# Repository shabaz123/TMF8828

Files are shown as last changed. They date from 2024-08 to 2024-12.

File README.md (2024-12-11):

# TMF8828 Multi-Zone Time-of-Flight Sensor

# Introduction
This repository contains a project (hardware and software) related to the TMF8828 sensor. 

[Click here for information regarding the TMF8828](https://community.element14.com/products/manufacturers/ams_osram/b/blog/posts/engineer-to-engineer-understanding-time-of-flight-sensing).

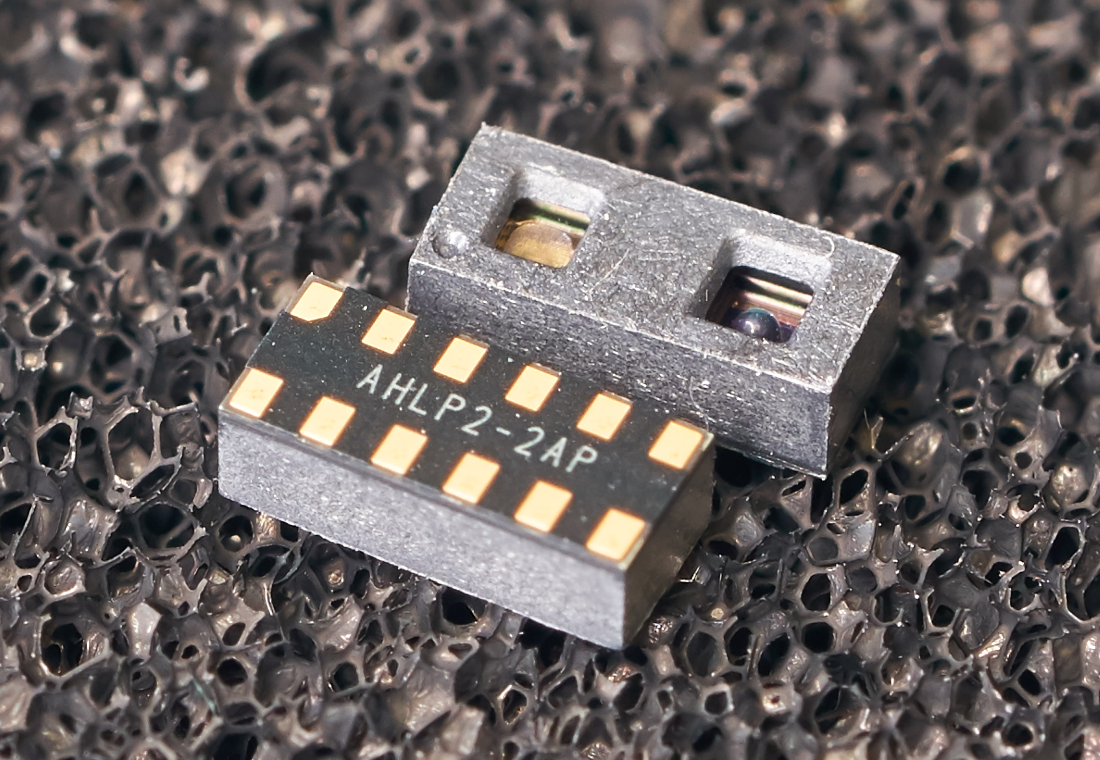
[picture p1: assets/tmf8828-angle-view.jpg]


**Caution**
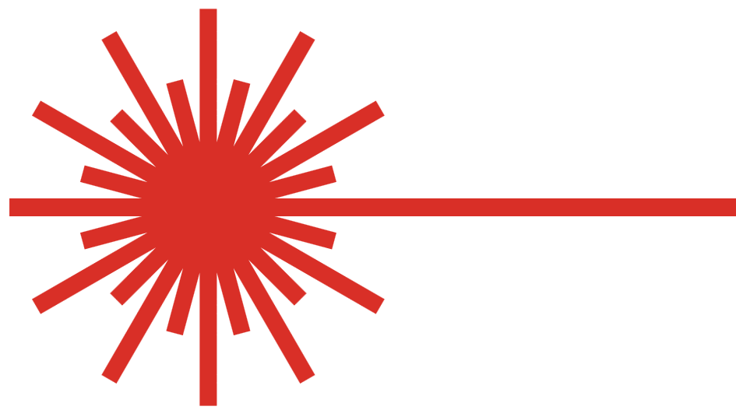
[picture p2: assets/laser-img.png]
 The device contains a laser. In the photo above, the aperture on the left (lighter color) contains the laser. The darker aperture on the right contains the sensor array.

# Circuit Diagram
The circuit shown below can be assembled onto a small board. It is designed to either interface with a Pi Pico board, or, alternatively, any other microcontroller with a 3.3V I2C interface. 

Some components are labeled DNF (Do Not Fit), depending on if you intend to use the board with a Pi Pico or with a different board.
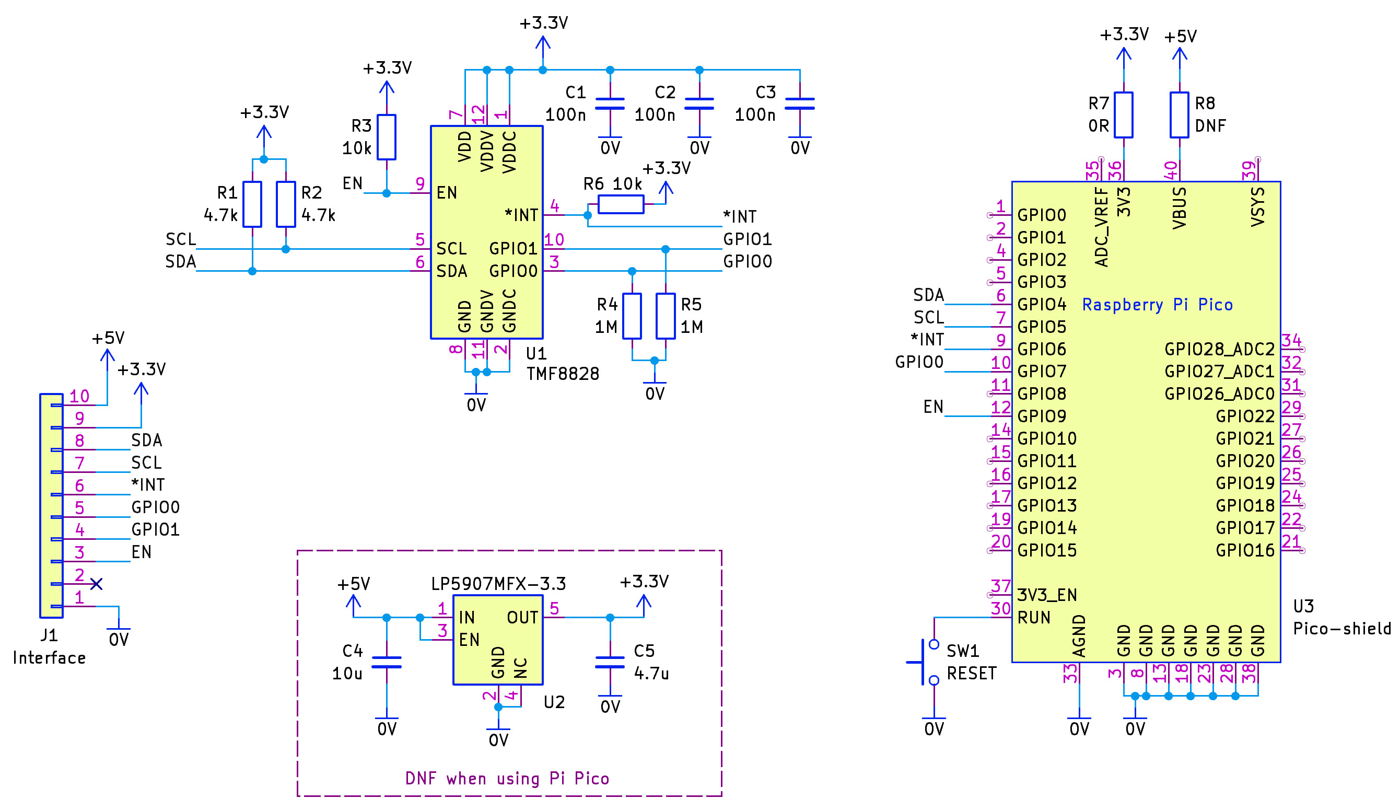
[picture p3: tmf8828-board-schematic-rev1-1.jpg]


Note: The diagram shown is for revision 1.1. The only difference between rev 1.0 and rev 1.1 is that the later revision connects the TMF8828 EN pin to GPIO9 on the Pi Pico. In rev 1.0, that connection was missing.

# PCB Layout
The KiCad files (requires KiCad V8.0 upward) are in the repo, as well as the generated Gerber files, ready for sending to a PCB factory. 

Currently, there are no known errors, but it has not undergone much testing beyond basic board bring-up, and running some code that appears to provide a response from the sensor.
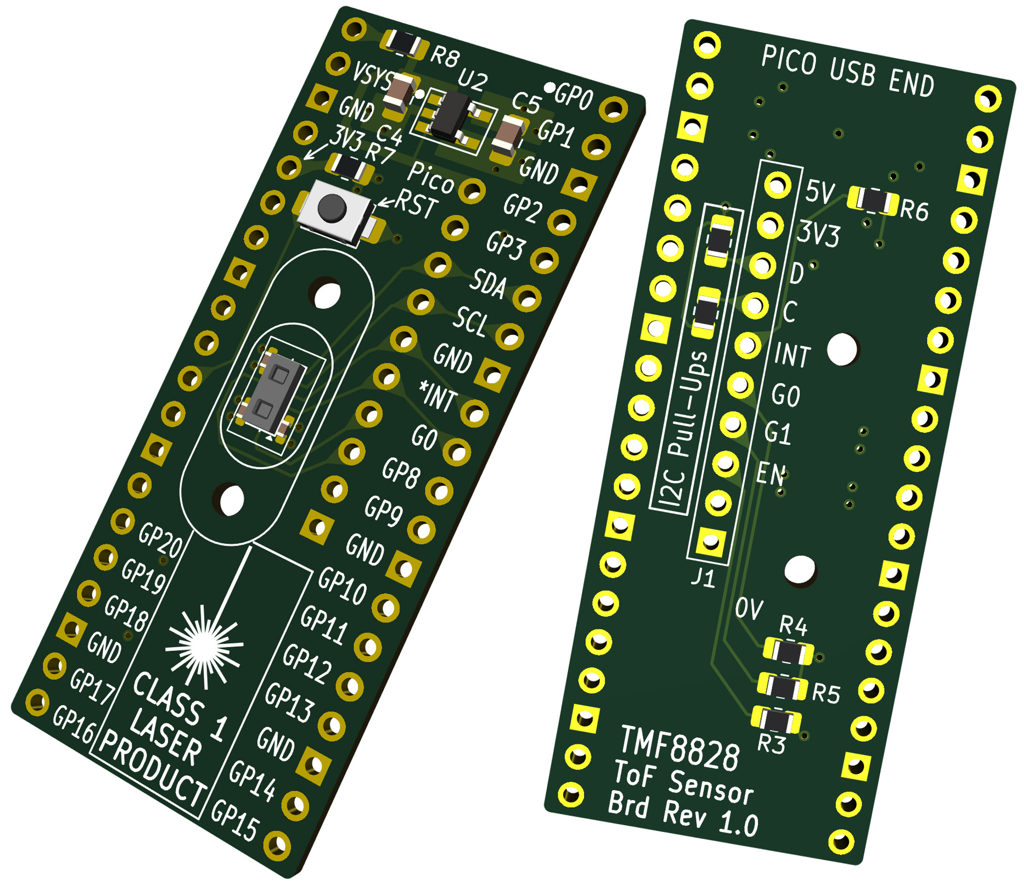
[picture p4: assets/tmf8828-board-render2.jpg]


# Source Code
The tmf8828_experiment_board folder contains a Pi Pico project (requires the [Pi Pico C/C++ SDK](https://www.raspberrypi.com/documentation/microcontrollers/c_sdk.html)). 

After building the code (follow the Pi Pico C/C++ SDK user instructions), hold down the BOOTSEL button on the Pi Pico, plug in the USB cable into the PC, release the BOOTSEL button, and then drag across the built .uf2 file onto the USB drive letter that appeared. The firmware will be uploaded into the Pi Pico, and it will automatically start running the code. 

The device will present a serial port, which can be opened using an serial console software, at 115200 baud, to see a stream of data in text form. 

The source code is based on the Unified Arduino driver for TMF8820/24/28 available under the **Software** section at the [AMS TMF8828 web page](https://ams-osram.com/products/sensors/direct-time-of-flight-sensors-dtof/ams-tmf8828-configurable-8x8-multi-zone-time-of-flight-sensor), and a modification of it from https://github.com/Zalmotek/renesas-ams-osram-pmod1/tree/main/firmware/C/TMF8828

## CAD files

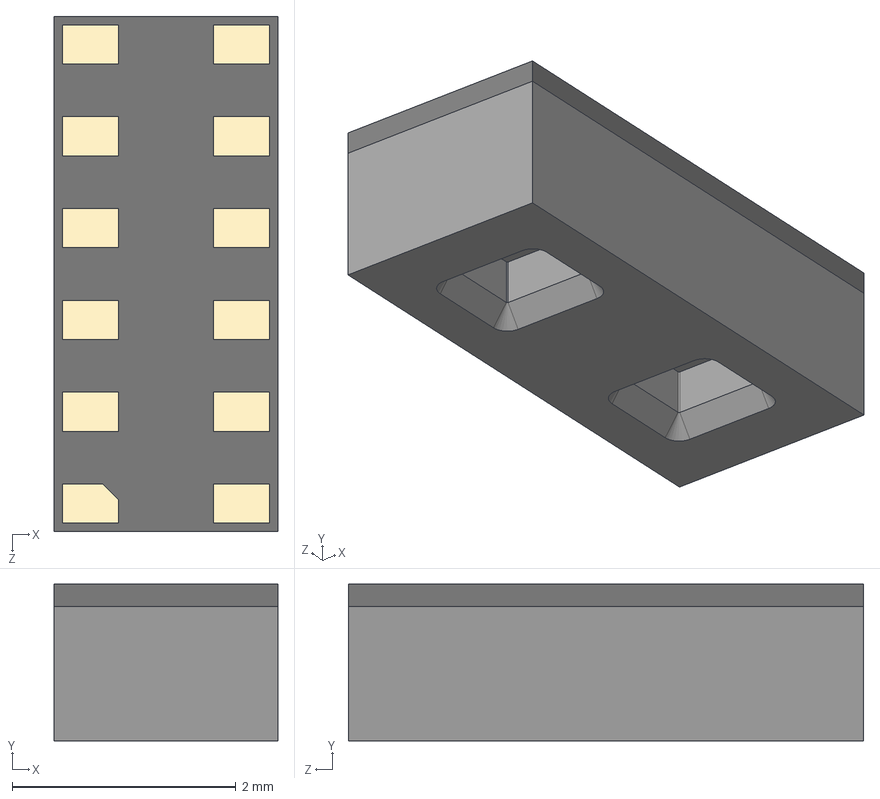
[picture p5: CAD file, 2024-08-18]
TMF8828-3D-Model.stp
2.00 x 1.40 x 4.60 mm

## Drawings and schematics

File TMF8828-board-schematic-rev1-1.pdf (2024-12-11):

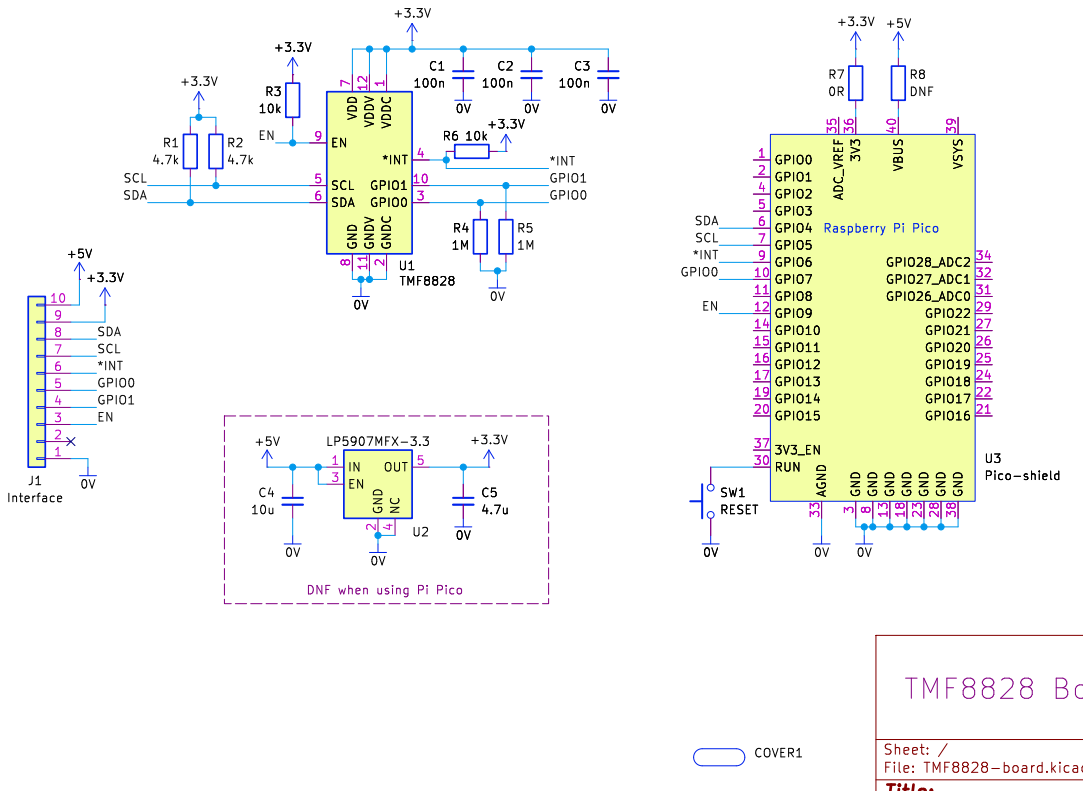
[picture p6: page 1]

Id: 1/1 Title: File: TMF8828-board.kicad_sch Sheet: /

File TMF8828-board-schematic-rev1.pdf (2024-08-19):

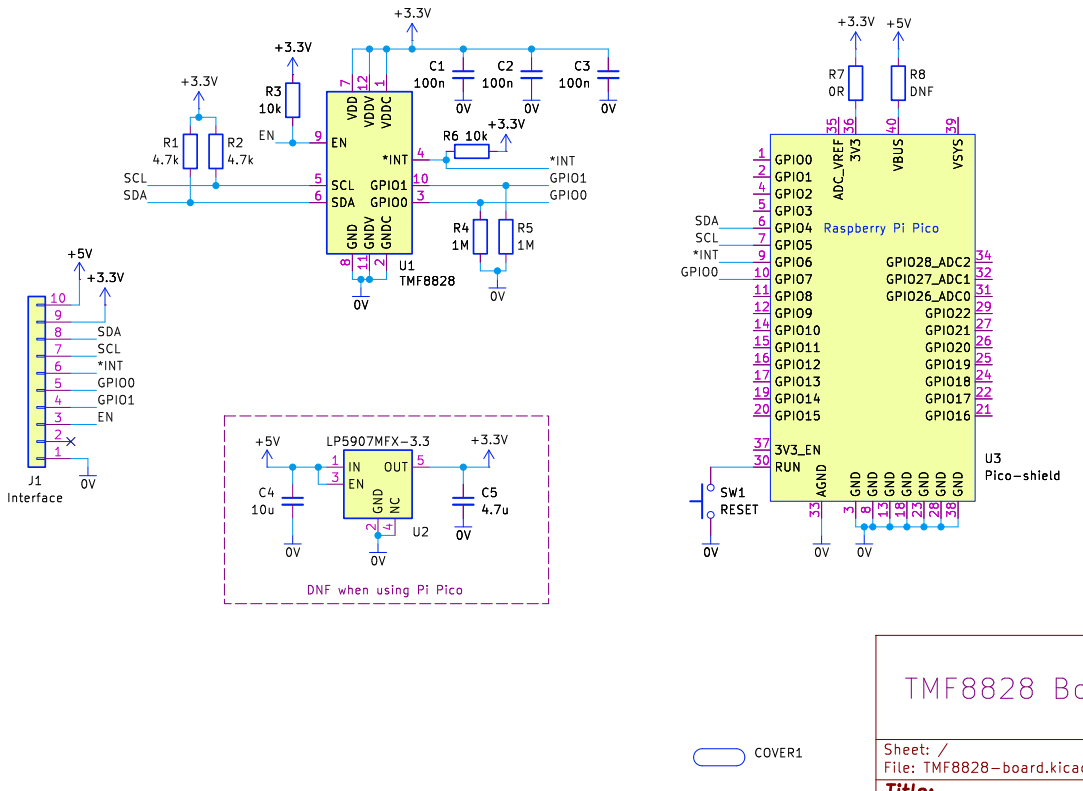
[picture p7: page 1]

Id: 1/1 Title: File: TMF8828-board.kicad_sch Sheet: /

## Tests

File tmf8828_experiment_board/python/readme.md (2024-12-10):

# These are python files for the talk to arduino via python

Python version 3.6 or higher is required.

## Virtual environment

Recommendation is to set-up a virtual environment. Open you favorite Windows PowerShell, VisualStudio Code or Spyder.
To install a virtual environement named env, and use it:
python -m venv env     
./env/Scripts/Activate.ps1    

## Requirements

pip install -r ./requirements.txt

## Scripts 

Please check on which COM port the Arduino is connected to your PC. Correct the com port in the python script to match
your PC.

To run a simple python script do this:

python talk_to_3_arduino_1MBaud.py

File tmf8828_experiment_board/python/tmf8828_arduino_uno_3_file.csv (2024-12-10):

Tmf8828 Arduino Uno + 2 tmf8828
#Vers | 3.224.52.27
#Vers | 3.224.52.27
#Conf | Period=132ms | KIter=250
#Obj | 67 | 0 | 21 | 16 | 239649 | 29 | 132 | 35 | 131 | 36 | 136 | 29 | 140 | 22 | 141 | 20 | 143 | 38 | 121 | 48 | 123 | 0 | 0 | 28 | 130 | 34 | 133 | 33 | 140 | 30 | 133 | 18 | 144 | 33 | 142 | 36 | 122 | 50 | 118 | 0 | 0 | 0 | 0 | 0 | 0 | 0 | 0 | 0 | 0 | 0 | 0 | 0 | 0 | 0 | 0 | 0 | 0 | 0 | 0
#Obj | 66 | 0 | 22 | 16 | 293593 | 33 | 129 | 46 | 130 | 43 | 136 | 31 | 141 | 30 | 143 | 26 | 145 | 45 | 113 | 47 | 111 | 0 | 0 | 32 | 131 | 46 | 130 | 41 | 141 | 32 | 132 | 22 | 144 | 40 | 140 | 44 | 113 | 48 | 110 | 0 | 0 | 0 | 0 | 0 | 0 | 0 | 0 | 0 | 0 | 0 | 0 | 0 | 0 | 0 | 0 | 0 | 0 | 0 | 0
#Obj | 65 | 0 | 22 | 0 | 344789 | 0 | 0 | 0 | 0 | 0 | 0 | 0 | 0 | 0 | 0 | 0 | 0 | 0 | 0 | 0 | 0 | 0 | 0 | 0 | 0 | 0 | 0 | 0 | 0 | 0 | 0 | 0 | 0 | 0 | 0 | 0 | 0 | 0 | 0 | 0 | 0 | 0 | 0 | 0 | 0 | 0 | 0 | 0 | 0 | 0 | 0 | 0 | 0 | 0 | 0 | 0 | 0 | 0 | 0
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

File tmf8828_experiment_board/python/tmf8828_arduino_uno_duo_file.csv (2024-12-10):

Tmf8828 Arduino Uno + 2 tmf8828
#Vers | 3.224.52.27
#Conf | Period=132ms | KIter=250
#Obj | 66 | 0 | 21 | 16 | 238425 | 28 | 255 | 40 | 255 | 37 | 255 | 31 | 255 | 25 | 255 | 20 | 255 | 40 | 255 | 40 | 255 | 0 | 0 | 29 | 255 | 39 | 255 | 38 | 255 | 33 | 255 | 18 | 255 | 32 | 255 | 42 | 255 | 42 | 255 | 0 | 0 | 0 | 0 | 0 | 0 | 0 | 0 | 0 | 0 | 0 | 0 | 0 | 0 | 0 | 0 | 0 | 0 | 0 | 0
#Obj | 65 | 0 | 20 | 13 | 292045 | 0 | 0 | 0 | 0 | 0 | 0 | 1819 | 28 | 1873 | 15 | 787 | 10 | 0 | 0 | 1840 | 23 | 0 | 0 | 0 | 0 | 0 | 0 | 1856 | 14 | 1831 | 17 | 820 | 10 | 1799 | 55 | 843 | 8 | 1852 | 15 | 0 | 0 | 0 | 0 | 0 | 0 | 0 | 0 | 0 | 0 | 0 | 0 | 1787 | 70 | 0 | 0 | 0 | 0 | 0 | 0
#Obj | 66 | 1 | 21 | 16 | 473017 | 29 | 255 | 39 | 255 | 37 | 255 | 32 | 255 | 13 | 255 | 42 | 255 | 39 | 255 | 42 | 255 | 0 | 0 | 27 | 255 | 38 | 255 | 35 | 255 | 32 | 255 | 13 | 255 | 41 | 255 | 37 | 255 | 42 | 255 | 0 | 0 | 0 | 0 | 0 | 0 | 0 | 0 | 0 | 0 | 0 | 0 | 0 | 0 | 0 | 0 | 0 | 0 | 0 | 0
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

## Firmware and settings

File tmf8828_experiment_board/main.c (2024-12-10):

/******************************
 * main.c
 * rev 1.0 Sep 2024 shabaz
 * ****************************/

#include <stdio.h>
#include <string.h>
#include "pico/stdlib.h"
#include "extrafunc.h"
#include "hardware/gpio.h"
#include "tmf8828.h"
#include "tmf8828_image.h"
#include "tmf8828_calib.h"
#include "tmf8828_shim.h"
#include "tmf8828_sensor.h"

// definitions
// set to 0 to run a simple app
// set to 1 to run the evaluation mode similar to the Arduino version from the manufacturer
#define EVAL_MODE 1

#define TOKEN_RESULT_ERROR 0
#define TOKEN_RESULT_OK 1
#define TOKEN_RESULT_LINE_COMPLETE 2
#define TOKEN_PROGRESS_NONE 0
#define TOKEN_PROGRESS_SEND 1
#define TOKEN_PROGRESS_RECV 2

// eval mode tmf states
#define TMF8828_STATE_DISABLED      0
#define TMF8828_STATE_STANDBY       1
#define TMF8828_STATE_STOPPED       2
#define TMF8828_STATE_MEASURE       3
#define TMF8828_STATE_ERROR         4


#define COL_RED printf("\033[31m")
#define COL_GREEN printf("\033[32m")
#define COL_YELLOW printf("\033[33m")
#define COL_BLUE printf("\033[34m")
#define COL_MAGENTA printf("\033[35m")
#define COL_CYAN printf("\033[36m")
#define COL_RESET printf("\033[0m")

// constants

// eval mode constants
extern const uint16_t configPeriod[3];
extern const uint16_t configKiloIter[3];
const uint8_t  configSpadId[3] = {15, 15, 15};
const uint16_t configLowThreshold = 100; // set the lower threshold to 10cm
const uint16_t configHighThreshold = 500; // set the upper threshold to 50cm
// select perstistence to be: 0==report every distance, even no distance; 1== report every distance that is a distance, 3== report distance only if 3x in range
const uint8_t configPersistance[3] = { 0, 1, 3 };
#define NR_LOG_LEVELS           7
// to increase/decrease logging
const uint8_t logLevels[ NR_LOG_LEVELS ] =
        { LOG_LEVEL_NONE,
          LOG_LEVEL_ERROR,
          LOG_LEVEL_CLK_CORRECTION,
          LOG_LEVEL_INFO,
          LOG_LEVEL_VERBOSE,
          LOG_LEVEL_I2C,
          LOG_LEVEL_DEBUG
        };

// global variables

uint8_t uart_buffer[305];
uint16_t uart_buffer_index = 0;
uint8_t do_echo = 1;
uint8_t token_progress = TOKEN_PROGRESS_NONE;
int expected_num = 0;
uint8_t byte_buffer[256];
uint8_t byte_buffer_index = 0;
uint16_t loop_tick = 0;

// eval mode global variables
//tmf8828Driver tmf8828[1];
extern tmf8828Driver tmf8828; // defined in tmf8828.c
extern int8_t stateTmf8828;              // current state of the device
extern int8_t configNr;                  // this sample application has only a few configurations it will loop through, the variable keeps track of that
int8_t persistenceNr;             // this is to keep track of the selected persistence setting (out of three for this sample application)
extern int8_t clkCorrectionOn;           // if non-zero clock correction is on
extern int8_t dumpHistogramOn;           // if non-zero, dump all histograms
uint8_t logLevelIdx;              // log level index into logLevels array
volatile uint8_t irqTriggered;    // interrupt is triggered or not
extern const unsigned long tmf8828_image_termination;
extern const unsigned long tmf8828_image_start;
extern const unsigned long tmf8828_image_finish;
extern const unsigned long tmf8828_image_length;
extern const unsigned char tmf8828_image[7128];
extern const uint8_t tmf8828_calib_0[192];
extern const uint8_t tmf8828_calib_1[192];
extern const uint8_t tmf8828_calib_2[192];
extern const uint8_t tmf8828_calib_3[192];



/************* prototypes ***************/
// eval mode prototypes
void eval_mode(void);
void print_eval_menu(void);

/************* functions ***************/

// print_buf_hex prints a buffer in hex format, up to 304 bytes
// 000: 00 01 02 03 04 05 06 07 08 09 0A 0B 0C 0D 0E 0F : 0123456789ABCDEF
void
print_buf_hex(uint8_t *buf, uint16_t len) {
    uint16_t i, j;
    uint8_t c;
    uint8_t index = 0;

    for (i = 0; i < len; i += 16) {
        COL_BLUE;
        printf("%03d: ", index);
        COL_CYAN;
        for (j = 0; j < 16; j++) {
            if (i + j < len) {
                printf("%02X ", buf[i + j]);
            } else {
                printf("   ");
            }
        }
        COL_BLUE;
        printf(": ");
        COL_GREEN;
        for (j = 0; j < 16; j++) {
            if (i + j < len) {
                c = buf[i + j];
                if ((c < 32) || (c > 126)) {
                    printf(".");
                } else {
                    printf("%c", c);
                }
            } else {
                printf(" ");
            }
        }
        printf("\n");
        index += 16;
    }
    COL_RESET;
}



// scan_uart_input fill the uart_buffer until a newline is received
// returns number of bytes if a newline is received, 0 otherwise
int
scan_uart_input(void) {
    int c;
    uint16_t num_bytes;
    c = getchar_timeout_us(1000);
    if (c == PICO_ERROR_TIMEOUT) {
        return 0;
    }

    if ((c == 8) || (c==127)) { // backspace pressed
        if (uart_buffer_index > 0) {
            uart_buffer_index--;
            if (do_echo) {
                putchar(8);
                putchar(' ');
                putchar(8);
            }
        }
        return 0;
    }
    if (c == 13) {
        // add a space to simplify token parsing
        uart_buffer[uart_buffer_index++] = ' ';
        uart_buffer[uart_buffer_index] = 0;
        num_bytes = uart_buffer_index;
        uart_buffer_index = 0;
        if (do_echo) {
            printf("\n");
        }
        return num_bytes;
    }
    uart_buffer[uart_buffer_index] = (uint8_t) c;
    if (do_echo) {
        putchar(c);
    }
    uart_buffer_index++;
    if (uart_buffer_index >= 300) {
        uart_buffer_index = 0;
    }
    return 0;
}

int decode_token(char *token) {
    unsigned int val;
    int retval = 0;
    if (strcmp(token, "device?") == 0) {
        printf("TMF8828 Experiment Board\n\r");
        // reset any state and variables
        token_progress = TOKEN_PROGRESS_NONE;
        expected_num = 0;
        byte_buffer_index = 0;
        return TOKEN_RESULT_LINE_COMPLETE;
    }
    if (strcmp(token, "recv") == 0) {
        if (expected_num == 0) {
            COL_RED;
            printf("No bytes expected\n");
            COL_RESET;
            return TOKEN_RESULT_LINE_COMPLETE;
        }
        byte_buffer_index = 0;
        retval = PICO_ERROR_GENERIC; // nothing to do for now
        if (retval == PICO_ERROR_GENERIC) {
            COL_RED;
            printf("No bytes read.\n");
            COL_RESET;
        } else {
            print_buf_hex(byte_buffer, expected_num);
        }
        return TOKEN_RESULT_LINE_COMPLETE;
    }
    if (strcmp(token, "end_tok") == 0) {
        return TOKEN_RESULT_LINE_COMPLETE;
    }
    // done
    COL_RED;
    printf("Unknown command: %s\n", token);
    COL_RESET;
    return TOKEN_RESULT_LINE_COMPLETE;
}

// Parse each space-separated token
int process_line(uint8_t *buf, uint16_t len) {
    int res;
    char token[20];
    uint16_t i = 0;
    uint16_t j = 0;
    if (len == 0) {
        return TOKEN_RESULT_ERROR;
    }
    while (i < len) {
        if (buf[i] == ' ') {
            token[j] = 0;
            //printf("token: %s\n", token);
            res = decode_token(token);
            if (res == TOKEN_RESULT_LINE_COMPLETE) {
                return TOKEN_RESULT_LINE_COMPLETE;
            }
            j = 0;
        } else {
            token[j] = buf[i];
            j++;
        }
        i++;
    }
    res = decode_token("end_tok");
}

int
main(void)
{
    int numbytes;

    stdio_init_all();
    sleep_ms(3000);
    led_setup();
    printf("TMF8828 Experiment Board\n");
    configurePins();
    if (EVAL_MODE) {
        eval_mode(); // this does not return
    }
    // the rest of the code here is a simple app example
    TMF8828_constructor();
    TMF8828_factoryCalibration(0, false); //must precede the startMeasuring function
    TMF8828_startMeasuring();

    printf("Starting main loop\n");
    while (true) {
        numbytes = scan_uart_input();
        if (numbytes > 0) {
            process_line(uart_buffer, numbytes);
        }
        if (loop_tick > 499) {
            loop_tick = 0;
            led_toggle();
            // print 8x8
            int obj0conf[8][8], obj0dist[8][8], obj1conf[8][8], obj1dist[8][8];
            if (TMF8828_update8x8(obj0conf, obj0dist, obj1conf, obj1dist)) {
                APP_PRINT("\nObject0 matrix\n");
                for (int i = 0; i < 8; i++) {
                    for (int j = 0; j < 8; j++) {
                        APP_PRINT("%d, ", obj0dist[i][j]);
                    }
                    APP_PRINT("\n");
                }
                APP_PRINT("\nObject1 matrix\n");
                for (int i = 0; i < 8; i++) {
                    for (int j = 0; j < 8; j++) {
                        APP_PRINT("%d, ", obj1dist[i][j]);
                    }
                    APP_PRINT("\n");
                }
            }
        }
        sleep_ms(1);
        loop_tick++;
    }
    return 0; // OK for warning on this line (unreachable code)
}

// **************************************************************
// ********************** Eval Mode *****************************
// **************************************************************

void resetAppState ( )
{
    stateTmf8828 = TMF8828_STATE_DISABLED;
    configNr = 0;        // rotate through the given configurations
    persistenceNr = 0;
    clkCorrectionOn = 1;
    dumpHistogramOn = 0; // default is off
    irqTriggered = 0;
}

void wakeup ( )
{
    if ( stateTmf8828 == TMF8828_STATE_STANDBY ){
        tmf8828Wakeup( &(tmf8828) );
        if ( tmf8828IsCpuReady( &(tmf8828), CPU_READY_TIME_MS ) ){
            stateTmf8828 = TMF8828_STATE_STOPPED;
        } else {
            stateTmf8828 = TMF8828_STATE_ERROR;
        }
    }
}

// execute a stop
void stop ( )
{
    if ( stateTmf8828 == TMF8828_STATE_MEASURE || stateTmf8828 == TMF8828_STATE_STOPPED )
    {
        tmf8828StopMeasurement( &(tmf8828) );
        tmf8828DisableInterrupts( &(tmf8828), 0xFF );               // just disable all
        stateTmf8828 = TMF8828_STATE_STOPPED;
    }
}

void printDeviceInfo ( )
{
    printf(  "Driver " );
    PRINT_INT( tmf8828.info.version[0] ); PRINT_CHAR( '.' );
    PRINT_INT( tmf8828.info.version[1] );
    printf(  " FW " );
    PRINT_INT( tmf8828.device.appVersion[0] ); PRINT_CHAR( '.' );
    PRINT_INT( tmf8828.device.appVersion[1] ); PRINT_CHAR( '.' );
    PRINT_INT( tmf8828.device.appVersion[2] ); PRINT_CHAR( '.' );
    PRINT_INT( tmf8828.device.appVersion[3] ); PRINT_CHAR( '.' );
    printf(  " Chip " );
    PRINT_INT( tmf8828.device.chipVersion[0] ); PRINT_CHAR( '.' );
    PRINT_INT( tmf8828.device.chipVersion[1] );
    printf(  " Serial 0x");
    printf( "%02x", tmf8828.device.deviceSerialNumber );
    PRINT_LN( );
}

// power down by setting PON=0
void powerDown ( )
{
    if ( stateTmf8828 == TMF8828_STATE_MEASURE ) {
        tmf8828StopMeasurement( &(tmf8828) ); // stop a measurement first
        tmf8828DisableInterrupts( &(tmf8828), 0xFF );               // just disable all
        stateTmf8828 = TMF8828_STATE_STOPPED;
    }
    if ( stateTmf8828 == TMF8828_STATE_STOPPED ) {
        tmf8828Standby( &(tmf8828) );
        stateTmf8828 = TMF8828_STATE_STANDBY;
    }
}

void nextConfiguration ( )
{
    if ( stateTmf8828 == TMF8828_STATE_STOPPED ) {
        configNr = configNr + 1;
        if ( configNr > 2 ) {
            configNr = 0;     // wrap around
        }
        configure();
    }
}

static const uint8_t * getPrecollectedFactoryCalibration ( uint8_t id )
{
    const uint8_t * factory_calib;

    factory_calib = tmf8828_calib_0;
    if ( id == 1 )
    {
        factory_calib = tmf8828_calib_1;
    }
    else if ( id == 2 )
    {
        factory_calib = tmf8828_calib_2;
    }
    else if ( id == 3 )
    {
        factory_calib = tmf8828_calib_3;
    }

    return factory_calib;
}

// enable device and download firmware
void enable ( uint32_t imageStartAddress, const unsigned char * image, int32_t imageSizeInBytes )
{
    if ( stateTmf8828 == TMF8828_STATE_DISABLED )
    {
        tmf8828EnableFn();
        sleep_ms(1);
        tmf8828ClkCorrection( &(tmf8828), clkCorrectionOn );
        tmf8828SetLogLevel( &(tmf8828), logLevels[ logLevelIdx ] );
        tmf8828Wakeup( &(tmf8828) );
        if ( tmf8828IsCpuReady( &(tmf8828), CPU_READY_TIME_MS ) )
        {
            if ( tmf8828DownloadFirmware( &(tmf8828)) == BL_SUCCESS_OK )
            {
                printf( " DWNL" );
                PRINT_LN( );
                resetAppState();
                tmf8828SwitchTo8x8Mode( &(tmf8828) );
                configure();
                stateTmf8828 = TMF8828_STATE_STOPPED;
                print_eval_menu(); // prints on UART usage and waits for user input on serial
                tmf8828ReadDeviceInfo( &(tmf8828) );
                printDeviceInfo( );
            }
            else
            {
                stateTmf8828 = TMF8828_STATE_ERROR;
            }
        }
        else
        {
            stateTmf8828 = TMF8828_STATE_ERROR;
        }
    } // else device is already enabled
    else
    {
        tmf8828ReadDeviceInfo( &(tmf8828) );
        printDeviceInfo( );
    }
}

// start measurement
void measure ( )
{
    if ( stateTmf8828 == TMF8828_STATE_STOPPED )
    {
        tmf8828ClrAndEnableInterrupts( &(tmf8828), TMF8828_APP_I2C_RESULT_IRQ_MASK | TMF8828_APP_I2C_RAW_HISTOGRAM_IRQ_MASK );
        tmf8828StartMeasurement( &(tmf8828) );
        stateTmf8828 = TMF8828_STATE_MEASURE;
    }
}

// execute factory calibration in state stopped only
void factoryCalibration ( )
{
    if ( stateTmf8828 == TMF8828_STATE_STOPPED ) {
        printf(  "Fact Cal\n");
        tmf8828ConfigureFull( &(tmf8828), 1, 4000, configSpadId[configNr], 0, 0xffff, 0, 0x3ffff, 0 );    // no histogram dumping in factory calibration allowed, 4M iterations for factory calibration recommended
        tmf8828ResetFactoryCalibration( &(tmf8828) );
        if (  APP_SUCCESS_OK == tmf8828FactoryCalibration( &(tmf8828) ) // walk through all 4 calibration
              && APP_SUCCESS_OK == tmf8828FactoryCalibration( &(tmf8828) )
              && APP_SUCCESS_OK == tmf8828FactoryCalibration( &(tmf8828) )
              && APP_SUCCESS_OK == tmf8828FactoryCalibration( &(tmf8828) ))
        {
            configure( );
            return;
        }
        printf(  "#Err,fact calib\n" );
    }
}

// load factory calibration page to I2C registers 0x20...
void loadFactoryCalibration ( )
{
    if ( stateTmf8828 == TMF8828_STATE_STOPPED )
    {

        tmf8828ResetFactoryCalibration( &(tmf8828) );
        tmf8828LoadConfigPageFactoryCalib( &(tmf8828) );
        printRegisters( 0x20, 0xE0-0x20, ',', 0 );
        tmf8828WriteConfigPage( &(tmf8828) );                // advance to next calib page
        tmf8828LoadConfigPageFactoryCalib( &(tmf8828) );
        printRegisters( 0x20, 0xE0-0x20, ',', 1 );
        tmf8828WriteConfigPage( &(tmf8828) );               // advance to next calib page
        tmf8828LoadConfigPageFactoryCalib( &(tmf8828) );
        printRegisters( 0x20, 0xE0-0x20, ',', 2 );
        tmf8828WriteConfigPage( &(tmf8828) );               // advance to next calib page
        tmf8828LoadConfigPageFactoryCalib( &(tmf8828) );
        printRegisters( 0x20, 0xE0-0x20, ',', 3 );
        tmf8828WriteConfigPage( &(tmf8828) );                // advance to next calib page

    }
}

// restore factory calibration for file tmf8828_calib.c
void restoreFactoryCalibration ( )
{
    if ( stateTmf8828 == TMF8828_STATE_STOPPED )
    {

        if (  APP_SUCCESS_OK == tmf8828ResetFactoryCalibration( &(tmf8828) )                                             // First reset, then load all 4 calib pages
              && APP_SUCCESS_OK == tmf8828SetStoredFactoryCalibration( &(tmf8828), getPrecollectedFactoryCalibration( 0 ) )
              && APP_SUCCESS_OK == tmf8828SetStoredFactoryCalibration( &(tmf8828), getPrecollectedFactoryCalibration( 1 ) )
              && APP_SUCCESS_OK == tmf8828SetStoredFactoryCalibration( &(tmf8828), getPrecollectedFactoryCalibration( 2 ) )
              && APP_SUCCESS_OK == tmf8828SetStoredFactoryCalibration( &(tmf8828), getPrecollectedFactoryCalibration( 3 ) )
                )
        {
            printf(  "Set fact cal" );
            PRINT_LN( );
            return;
        }


        printf(  "#Err" );
        PRINT_CHAR( ',' );
        printf(  "loadCal"  );
        PRINT_LN( );
    }
}

// enable/disable clock correction
void clockCorrection ( )
{
    clkCorrectionOn = !clkCorrectionOn;       // toggle clock correction on/off
    tmf8828ClkCorrection( &(tmf8828), clkCorrectionOn );
    printf(  "Clk corr is " );
    PRINT_INT( clkCorrectionOn );
    PRINT_LN( );
}

// configure histogram dumping (next dumping bit-mask)
void histogramDumping ( )
{
    if ( stateTmf8828 == TMF8828_STATE_STOPPED )
    {
        dumpHistogramOn = dumpHistogramOn + 1;       // select histogram dump on/off, and type of histogram dumping
        if ( dumpHistogramOn > (TMF8828_COM_HIST_DUMP__histogram__electrical_calibration_24_bit_histogram + TMF8828_COM_HIST_DUMP__histogram__raw_24_bit_histogram) )
        {
            dumpHistogramOn = 0; // is off again
        }
        configure( );
        printf(  "Histogram is " );
        PRINT_INT( dumpHistogramOn );
        PRINT_LN( );
    }
}

// set the thresholds to the next configuration
void thresholds ( )
{
    if ( stateTmf8828 == TMF8828_STATE_STOPPED )
    {
        persistenceNr = persistenceNr + 1;
        if ( persistenceNr > 2 )
        {
            persistenceNr = 0;     // wrap around
        }
        configure( );
    }
}

#ifdef NOT_REQUIRED
// Switch I2C address.
void changeI2CAddress ( )
{
    if ( stateTmf8828 == TMF8828_STATE_STOPPED )
    {
        uint8_t newAddr = tmf8828.i2cSlaveAddress;
        if ( newAddr == TMF8828_SLAVE_ADDR )
        {
            newAddr = TMF8828_SLAVE_ADDR + 1;      // use next i2c slave address
        }
        else
        {
            newAddr = TMF8828_SLAVE_ADDR;         // back to original
        }
        if ( tmf8828ChangeI2CAddress( &(tmf8828), newAddr ) != APP_SUCCESS_OK )
        {
            printf(  "#Err"  );
            PRINT_CHAR( ',' );
        }
    }
    printf(  "I2C Addr=" );
    PRINT_INT( tmf8828.i2cSlaveAddress );
    PRINT_LN( );
}
#endif

// decrease logging level
void logLevelDec ( )
{
    if ( logLevelIdx > 0 )
    {
        logLevelIdx--;
        tmf8828SetLogLevel( &(tmf8828), logLevels[ logLevelIdx ] );
    }
    printf(  "Log=" );
    PRINT_INT( logLevels[ logLevelIdx ] );
    PRINT_LN( );
}

// increase logging level
void logLevelInc ( )
{
    if ( logLevelIdx < NR_LOG_LEVELS - 1 )
    {
        logLevelIdx++;
        tmf8828SetLogLevel( &(tmf8828), logLevels[ logLevelIdx ] );
    }
    printf(  "Log=" );
    PRINT_INT( logLevels[ logLevelIdx ] );
    PRINT_LN( );
}

// perform a hardware + software reset
void reset ( )
{
    if ( stateTmf8828 != TMF8828_STATE_DISABLED )
    {
        tmf8828Reset( &(tmf8828) );
        printf(  "Reset TMF8828" );
        PRINT_LN( );
        stateTmf8828 = TMF8828_STATE_STOPPED;
        tmf8828SwitchTo8x8Mode( &(tmf8828) );
    }
}

#ifdef NOT_REQUIRED
// Print the current state (stateTmf8828) in a readable format
void printState ( )
{

    printf(  "TMF8828" );

    printf(  " state="  );
    switch ( stateTmf8828 )
    {
        case TMF8828_STATE_DISABLED: printf(  "disabled" ); break;
        case TMF8828_STATE_STANDBY: printf(  "standby" ); break;
        case TMF8828_STATE_STOPPED: printf(  "stopped" ); break;
        case TMF8828_STATE_MEASURE: printf(  "measure" ); break;
        case TMF8828_STATE_ERROR: printf(  "error" ); break;
        default: printf(  "???" ); break;
    }
    PRINT_LN( );
}
#endif

void print_eval_menu(void) {
    printf(  "TMF8828 Pi Pico Driver\n" );
    printf(  "UART commands\n" );
    printf(  "a ... dump registers\n" );
    printf(  "c ... next configuration\n" );
    printf(  "d ... disable device\n" );
    printf(  "e ... enable device and download TMF8828 FW\n" );
    printf(  "f ... do fact calib\n" );
    printf(  "h ... help \n" );
    printf(  "i ... i2c addr. change\n" );
    printf(  "l ... load fact calib\n" );
    printf(  "m ... measure\n" );
    printf(  "p ... power down\n" );
    printf(  "r ... restore fact calib from file\n" );
    printf(  "s ... stop measure\n" );
    printf(  "t ... next persistance set\n" );
    printf(  "w ... wakeup\n" );
    printf(  "x ... clock corr on/off\n" );
    printf(  "z ... histogram\n" );
    printf(  "+ ... log+\n" );
    printf(  "- ... log-\n" );
    printf(  "# ... reset\n" );
    printf(  "\n");
}
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

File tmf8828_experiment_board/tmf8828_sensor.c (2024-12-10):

//


#include "tmf8828_sensor.h"
#include "tmf8828_image.h"
#include "registers_i2c.h"
#include "tmf8828_shim.h"

extern const unsigned long tmf8828_image_termination;
extern const unsigned long tmf8828_image_start;
extern const unsigned long tmf8828_image_finish;
extern const unsigned long tmf8828_image_length;
extern const unsigned char tmf8828_image[7128];

// Driver Version
const tmf8828DriverInfo tmf8828DriverInfoReset =
        { .version = { TMF8828_DRIVER_MAJOR_VERSION , TMF8828_DRIVER_MINOR_VERSION }
        };

const tmf8828DeviceInfo tmf8828DeviceInfoReset =
        { .deviceSerialNumber = 0
                , .appVersion = { 0, 0, 0, 0 }
                , .chipVersion = { 0, 0}
        };



uint8_t dataBuffer[ DATA_BUFFER_SIZE ];           // transfer/receive buffer

static void tmf8828ResetClockCorrection( tmf8828Driver * driver );

void tmf8828Initialise ( tmf8828Driver * driver, uint8_t enablePin, uint8_t interruptPin )
{
    i2c_setup();
    tmf8828ResetClockCorrection( driver );
    driver->enablePin = enablePin;
    driver->interruptPin = interruptPin;
    driver->i2cSlaveAddress = TMF8828_SLAVE_ADDR;
    driver->clkCorrectionEnable = 1;                  // default is on
    driver->logLevel = LOG_LEVEL_ERROR;
}

// function reads complete device information from the tmf8806
int8_t tmf8828ReadDeviceInfo ( tmf8828Driver * driver )
{
    driver->device = tmf8828DeviceInfoReset;
    i2cRxReg( driver, driver->i2cSlaveAddress, TMF8828_ID, 2, driver->device.chipVersion );
    i2cRxReg( driver, driver->i2cSlaveAddress, TMF8828_COM_APP_ID, 4, driver->device.appVersion );  // tmf8828 application has 4 verion bytes
    if ( driver->device.appVersion[0] == TMF8828_COM_APP_ID__application )
    {
        i2cRxReg( driver, driver->i2cSlaveAddress, TMF8828_COM_SERIAL_NUMBER_0, 4, dataBuffer );
        driver->device.deviceSerialNumber = tmf8828GetUint32( &(dataBuffer[0]) );
    }
    return APP_SUCCESS_OK;
}

// Function to overwrite the default log level
void tmf8828SetLogLevel ( tmf8828Driver * driver, uint8_t level )
{
    driver->logLevel = level;
}

// Function to set clock correction on or off.
// enable ... if <>0 clock correction is enabled (default)
// enable ... if ==0 clock correction is disabled
void tmf8828ClkCorrection ( tmf8828Driver * driver, uint8_t enable )
{
    driver->clkCorrectionEnable = !!enable;
}

// Function executes a reset of the device
void tmf8828Reset ( tmf8828Driver * driver )
{
    i2c_setup();
    dataBuffer[0] = RESETREASON__soft_reset__MASK;
    i2c_tx( driver->i2cSlaveAddress, RESETREASON, dataBuffer, 1 );
    if ( driver->logLevel >= LOG_LEVEL_VERBOSE )
    {
        PRINT_STR( "reset" );
        PRINT_LN( );
    }
    tmf8828ResetClockCorrection( driver );
}

void tmf8828Enable ( tmf8828Driver * driver )
{
    tmf8828Initialise( driver, driver->enablePin, driver->interruptPin );           // when enable gets high, the HW resets to default slave addr
}

// function prints a single result, and returns incremented pointer
static uint8_t * print_result ( tmf8828Driver * driver, uint8_t * data, int *conf, int *dist, int *idx )
{
    uint8_t confidence = data[0];               // 1st byte is confidence
    uint16_t distance = data[2];                // 3rd byte is MSB distance
    distance = (distance << 8);       // 2nd byte is LSB distnace
    distance = distance + data[1];
    distance = tmf8828CorrectDistance( driver, distance );
    //PRINT_CHAR( SEPERATOR );
    //PRINT_INT( distance );
    //PRINT_CHAR( SEPERATOR );
    //PRINT_INT( confidence );
    int offset = 0;
    if ((*idx) > 35) {
        offset = 4;
    }
    else if ((*idx) > 26) {
        offset = 3;
    }
    else if ((*idx) > 17) {
        offset = 2;
    }
    else if ((*idx) > 8){
        offset = 1;
    }
    conf[(*idx) - offset] = confidence;
    dist[(*idx) - offset] = distance;
    (*idx)++;
    return data+3;                              // for convenience only, return the new pointer
}

// Results printing:
// #Obj,<i2c_slave_address>,<result_number>,<temperature>,<number_valid_results>,<systick>,<distance_0_mm>,<confidence_0>,<distance_1_mm>,<distance_1>, ...
void print_results ( tmf8828Driver * driver, uint8_t * data, uint8_t len, int *conf, int *dist, int *subcapture_nr )
{
    if ( len >= TMF8828_COM_CONFIG_RESULT__measurement_result_size )
    {
        int cnt = 0;
        int8_t i;
        //uint32_t sysTick = tmf8828GetUint32( data + RESULT_REG( SYS_TICK_0 ) );
        //PRINT_STR( "#Obj" );
        //PRINT_CHAR( SEPERATOR );
        //PRINT_INT( driver->i2cSlaveAddress );
        //PRINT_CHAR( SEPERATOR );
        //PRINT_INT( data[ RESULT_REG( RESULT_NUMBER) ] );
        (*subcapture_nr) = data[ RESULT_REG( RESULT_NUMBER) ];
        //PRINT_CHAR( SEPERATOR );
        //PRINT_INT( data[ RESULT_REG( TEMPERATURE )] );
        //PRINT_CHAR( SEPERATOR );
        //PRINT_INT( data[ RESULT_REG( NUMBER_VALID_RESULTS )] );
        //PRINT_CHAR( SEPERATOR );
        //PRINT_INT( sysTick );
        data = data + RESULT_REG( RES_CONFIDENCE_0 );
        for ( i = 0; i < PRINT_NUMBER_RESULTS ; i++ )
        {
            data = print_result( driver, data, conf, dist, &cnt );
        }
        //PRINT_LN( );
    }
    else // result structure too short
    {
        PRINT_STR( "#Err" );
        PRINT_CHAR( SEPERATOR );
        PRINT_STR( "result too short" );
        PRINT_CHAR( SEPERATOR );
        PRINT_INT( len );
        PRINT_LN( );
    }
}

// Print histograms:
// #Raw,<i2c_slave_address>,<sub_packet_number>,<data_0>,<data_1>,..,,<data_127>
// #Cal,<i2c_slave_address>,<sub_packet_number>,<data_0>,<data_1>,..,,<data_127>
void print_histogram ( tmf8828Driver * driver, uint8_t * data, uint8_t len )
{
    if ( len >= TMF8828_COM_HISTOGRAM_PACKET_SIZE )
    {
        uint8_t i;
        uint8_t * ptr = &( data[ RESULT_REG( SUBPACKET_PAYLOAD_0 ) ] );
        if ( data[0] & TMF8828_COM_HIST_DUMP__histogram__raw_24_bit_histogram )
        {
            PRINT_STR( "#Raw" );
        }
        else if ( data[0] & TMF8828_COM_HIST_DUMP__histogram__electrical_calibration_24_bit_histogram )
        {
            PRINT_STR( "#Cal" );
        }
        else
        {
            PRINT_STR( "#???" );
        }
        PRINT_CHAR( SEPERATOR );
        PRINT_INT( driver->i2cSlaveAddress );
        PRINT_CHAR( SEPERATOR );
        PRINT_INT( data[ RESULT_REG( SUBPACKET_NUMBER ) ] );          // print the sub-packet number indicating the third-of-a-channel/tdc the histogram belongs to

        for ( i = 0; i < TMF8828_NUMBER_OF_BINS_PER_CHANNEL ; i++, ptr++ )
        {
            PRINT_CHAR( SEPERATOR );
            PRINT_INT( *ptr );
        }
        PRINT_LN( );
    }
    // else structure too short
}
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
